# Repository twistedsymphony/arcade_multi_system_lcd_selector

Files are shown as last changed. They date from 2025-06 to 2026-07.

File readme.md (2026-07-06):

# twistedsymphony's universal multi-kit LCD Selector (aka CAERTF-MS)

# F.A.Q.

**What is this thing?**

This is a small remote selector that can be adapted and used on DIP-switch based arcade multi-systems. 
Once the device is configured and installed, rather than selecting your game by setting dip switches, users can push the "Up" (D0) and "Down" (D2) buttons to navigate visually through the game list, then push "Select" (D1) to select the game. The selector will then hold the arcade board in reset and electrically configure the dip switches before releasing reset allowing the selected game to boot.
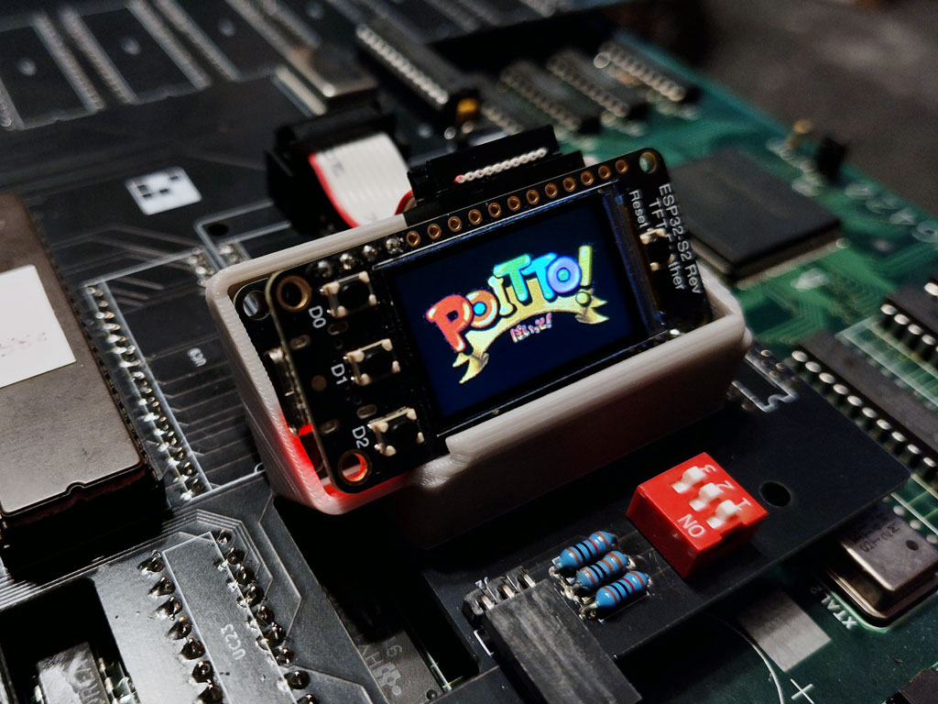
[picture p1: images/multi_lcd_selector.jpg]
multi_lcd_selector


**What is a DIP-switch based arcade multi-system?**

It's pretty niche, but some arcade games share the same electronics and only really have differing software. Arcade Enthusiests have designed and built "multi-systems" that allow switching out the software so that rather than having a whole separate set of electronics for each game, one set of electronics can play multiple games. The simpliest of these multi-systems will often use Dip-switches to set the game, which is cheap and effective but can be quite clumsy and unintuitive to use.

**Why was this made?**

Selecting your game using dip-switches can be frustrating, annoying, and very much non-intuitive. You typically need to have a little chart near by that tells you how to set the dip switches for the game you want to play, and if you want to switch games you have to power everything down to change it. Doing this while your arcade PCB is inside of an arcade cabinet means you sometimes have to be a contortionist with night-vision and the dexterity of a bomb-diffusal expert just to change that game you're playing. A selector like this one, that is easy to use and understand, solves most of those problems. 

This is being made open source in the hopes that future multi-systems that get developed by anyone in the community can easily incorporate support for this benefiting both the functionality of their multi and the users in the community. 

**What features/functinoality does this have?**

You get a full-color TFT display to show the game logos, you get 3 buttons: up, down, and select, so you can scroll through the game list and select the game you'd like to play. Selecting the game displays a loading screen while it resets the PCB and virtually configures the dip switches for game you selected. If an image isn't found it it will display the title of the game as text on the screen, and can seemilessly scroll between text and image based entries. It uses a standard 10-pin IDC ribon cable connection to the multi so you can remote mount the selector outside the cab by simply buying a cable long enough for your setup.

Through the menu configuration file you can control:
* what image is displayed with each game
* what image to display for the loading screen
* what text is to be displayed if an image isn't available
* what the dip configuration is for each selection
* what order you would like the games to appear in (you can even have the same game appear multiple times, in multiple places or with multiple names or images if you like)
* which games you would like displayed in the list or not displayed in the list
* which game you would like to load by default when you first power on
* the amount of idle time before the menu to goes back to displaying the current running game if you scrolled without selecting anything and then stopped

See the section below on "reconfiguring the menu_config.json file" for details on how to adjust these settings.

future features:
* remember last game. The code has support to remember the last selected game on power down and select that game on next power up, but there's a bug that's preventing that from functioning
* Selection over WiFi from your phone or other devie. the selector has Wifi Support so this is possible, the software just needs to be built.

**How Difficult is this to setup and use?**

If you're designing and building a multi kit this will add exactly $0 to your production costs. For the bare minimum support you simply need to add a 10-pin header footprint to your PCB for the selector and a 1-pin header footprint for a reset wire. This adds no cost to production and maybe an hour (not even) of your time to add the header to your schematic and PCB layout. I've even provided pre-configured footprints to allow mounting of the selector directly to your PCB if you have the room for it. If you want stronger support still you can spend a few extra cents per PCB and solder in the headers to each of the footprints you added to make use of the LCD selector completely plug and play for your users.

If you're a user of multis the difficulty varies depending on the multi-kit, setting up the kit at most would require soldering of some simple through-hole parts. The selector itself uses an off-the-shelf display and MCU unit from Adafruit coupled with a custom designed interface PCB that is open source and you can send the design files out and have made completely, or find someone selling them. Installing the software is as simple as copying files over to a USB thumb drive.

**Can this be used on multi-kits that weren't designed for it?**

Potentially, from an electrical standpoint this can be used with any multikit design to select games by up to 7 dip-switches (or jumpers). The challenge is wiring it up in a way that doesn't look like a science-experiment, which will vary greatly depending on the multi. The software is fully customizable, in addition to the "menu" config file there is a separate "multi" config file that allows you to specify the parameters of the multi for the software to tailor itself for it's use without any code changes.

# Putting Together a Selector as a Multi-Kit User

## Building a Selector
To piece together a selector you need 3 parts:
1. An Adafruit ESP32-S2 Reverse TFT Feather, which can be [purchased directly from Adafruit](https://www.adafruit.com/product/5345)
2. An CAERTF-MS Interface PCB, the schematics footprint, BOM, and ready-to-go production files are available within this repo
3. a 10-pin IDC cable. Multi-kits designed for selector mounting using the footprints in this repo are designed to utilize a 1.5in (38mm) length cable which can be [purchased from Adafruit](https://www.adafruit.com/product/556) though any 10-pin (2x5 female to female) IDC cable should work.

the Adafruit ESP32-S2 Reverse TFT Feather unit includes 2 male pin header rows, you will need to solder these to the unit to allow it to plugin to the CAERTF-MS interface PCB. While looking at the LCD with USB port on the left you will want to solder the entire bottom row of pins and the first 4 pins on the top left to allow it to plug into a CAERTF-MS Interface PCB and complete the assembly. 

## Setting up a Software release on a new Selector.
1. With the selector disconnected from both the multi-kit and the CAERTF-MS interface board, and disconnected from any power source, connect a USB-C cable between the selctor and your PC. 
2. If this is the first time configuring the selector the display on the selector should say "Adafruit Feather" with some information about the button and "battery" voltages, this is just the default software loaded. On the back of the display you should see a green and blue LED and there is a small reset button next to the USB port, you'll want to click this button once to reset, then double click it to put it into bootloader mode. If successful you should see the screen change and your PC should recognize a USB storage device called "FTHRS2BOOT" If not, attempt the reset button sequence again (the timing between the first click to reset and the subsequent double click can be tricky to get right)
3. Copy the latest Circuit Python .UF2 file file to the root of the "FTHRS2BOOT" drive. You can [get this file from the circuitpython website]( https://circuitpython.org/board/adafruit_feather_esp32s2_reverse_tft/) (at the time of this writing 9.2.8 was the lastest version and known to work)
4. Once the file has been copied over, the display should automatically restart and it will display some small white text on the screen and you will now see a new USB storage device attached to your computer called "CIRCUITPY"
5. Copy the entire content of a release file over to the root folder of the CIRCUIT PY drive. your computer will likely ask if you want to overwrite code.py, select yes to overwrite.

Releases should include:
  * code.py from the he /source directory here on github 
  * multi_config.json and menu_config.json configuring the selector specificlly to your multi kit
  * a /lib folder with the adafruit_display_text library
  * a /images fold that includes the loading.bmp image along with .bmp images for each game the multi supports.
4. you can now test out the menu to make sure it has the games you expect and see how it functions before connecting it to your multi. If you'd like to ajust settings in "menu_config.json" file you can do so to configure the menu to your liking and confirm those changes work while you still have it hooked up to your PC. it is NOT recommended to adjust the multi_config.json settings as these determine the electrical configurain for the multi.
5. once you're done simply unplug the USB-C cable from the display and now the software on the selector is ready for the multi.

**NOTE: Do not connect the USB-C on the Selector at the same time the 10-pin connector is attached to the Multi PCB** Doing so risks damaging your USB host device. The interface PCB has some protections to help prevent voltage back-feed from the USB port to the Multi-PCB but there are no protections to stop voltage back feed from the multi-PCB to the USB port as such there is risk of damage to your USB Host device.

## Installing a Selector onto your Multi
1. Follow the steps above to build the selector hardware
2. Follow the steps above to install the software on the selector
3. Ensure that all Dips switches on your multi are set to "OFF" (0) and that any rotary selectors are set to position "0". Alternatively, you can completely remove any dips or rotary switches from your multi-PCB (if you set any of these switches to other positions it causes that dip to perminently register as "on" resuling in different selections being made other than the game you selected on the LCD selector)
3. Plug the Adafruit ESP32-S2 Reverse TFT Feather into the CAERTF-MS Interface PCB, Make sure the USB-C port is disconnected (**Do not connect the USB-C on the Selector at the same time the 10-pin connector is attached to the Multi-PCB** the interface PCB has some protections to help prevent voltage back-feed from the USB port to the Multi-PCB but there are no protections to stop voltage back feed from the multi-PCB to the USB port as such there is risk of damage to your USB Host device.)
4. Connect the 10-pin IDC cable between the selector and the appropriate header on your multi-PCB
5. (optional) Install any mounts or brackets that may be avalable for your particular multi

## Making Images for the Selector
Images for the selector should be 240x135 pixels and .bmp format. it's recommended to used 8-bit indexed color format for the .bmp as this should set the file size to 33kb for each image. This is small enough to support 32 images for multis with 5-dip switches (32 game slots) or less. For multis with 6 dips (64 game slots) or 7 dips (128 game slots) you will likely need to get creative with lower bit-depth color or use text rather than images for some games.

While BMP files are larger the processing speed required to decode .jpg or .png compression on images takes about 1-2 seconds per image load which dramatically slows down menu navigation making the game selection experience feel extremely laggy. BMP was chosen as it is essentially uncompressed and is able to load instantly and at 8-bit indexed color is still small enough to support images for all games on nearly all dip-switch based multis.

## reconfiguring the menu_config.json file
The Configuration files on this multi are stored in a json format. You can use any plain text editor (such as notepad) to edit a .json file. If the formatting is incorrect or if any value is set incorrectly the multi will display an error on the screen explaining the issue rather than booting to the menu. It's highly recommeded that you use an existing working menu_config.json file and modify when developing a configuration file for a new multi, or adjusting your preferences for an existing multi. this will help you understand the format and parameters.

"games" are identified with a text string, I use the mame rom name for simplicity and consistency but any string of text can be used so long as it's used consistently through the config file. image file paths are always from the root of the device, and by default will use the "/image/filename.bmp" path and format.

There are three sections to the menu_config.json file, the main configuration which describes how the menu functions, the "game_order" list which simply describe the order that the games will apepar in the menu, and the "gamedefs" list which describes each game, it's title, which image it uses, and it's hex value in dips or on a rotary selector.

The main config has the following value and parameter pairs:
* multi_name: [string] This is simply a string of text to help identify which multi the menu is for, it's not used by the multi at all and really just useful to human readers of the config file.
* default_game: [string] this is the game that will start by default when the multi is powered on, it must be set to a value that matches a game identifier in the gamedefs section. if you do not have a preference it is recommended to set this to which ever game occupies position 0 (all dips off) as that will allow initial board bring up about 2 seconds faster.
* retain_selection: [boolean] this is a true or false value, when true the default_game will be ignored and instead the last game selected when the multi was powered off will be selected by default on next power-on (currently this feature is not functioning)
* idle_timeout: [decimal] this is the number in seconds that when scrolling through the menu without selecting a game that the selector will consider "idle" and return the display to showing the currently loaded game. default value of: 10
* debounce_delay: [decimal] this is number in seconds that subsequent button presses will be ignored. necessary to prevent accidental double taps. default value of: 0.2
* loading_image: [string] the file name and path to the .bmp file that will be used for the loading image when loading a new game. If the file specified does not exist plain text will be displayed instead. default value of: "/images/loading.bmp"
* text_color: [string] the hex value describing the color of the text on the screen when text is displayed instead of an image. default value of "0xFFFFFF"
* left_margin: [integer] the left margin in pixels when text is used on screen instead of an image. default value of: 10
* top_margin: [integer] the top margin in pixels when text is used on screen instead of an image. default value of: 60

The game_order section is simply a json array of all of the game identifiers and the order you wish to see them displayed in the menu. the game identifiers must match those specified in the "gamedefs" section. You may opt to exclude games here if you do not want them to appear on the menu, similarly you can include games in the game order multiple times if you wish for them to appaer multiple times on the menu rotation. The selector offers infinite menu rotation in either direction so the last game appears before the first game and the first game appears after the last game when scrolling.

the gamedefs section is a nested object where gamedefs includes a game object for each game available on the selector. each game object is labeled with a game id. As mentioned above I recommend using mame rom names for the game id for simplicity and consistency, but anything can be used. the only rule is that each game object must have a unique name.

each game object has 3 values:
* title: [string] The display text for the game title to use if an image file is not available. Multiple games can have the same title, though it's not recommended as there would be now way to tell the entries apart when using the menu. This text can be as long as you like, it will auto-resize the text to fit. However long games will be harder to read.
* image: [string] the file name and path to the image file associated with the game. I recommend naming your image files the same as the game id for simplicity and consistency. Multiple games can use the same image, though it's not recommended as there would be no way to tell the entries apart when using the menu. See the section above for details on how to make appropriate images for the selector.
* dip_val: [string] this is the value in hex that identifies which position on a rotary selector, or which dip-switch configuration is associated with the particular game. So for instance for a 4 position dip-switch a value of "1" will be translated to a dip configuraiton of "0001" and a value of "C" will be translated to "1100". Multiple games can use the same dip postion. So you could for instance have a game appear twice with two different names or two different images but use the same dip value.

# Adding Support for this Selector to your Multi as a Multi-Kit Developer
If you're designing and building a multi kit this will add exactly $0 to your production costs. For the bare minimum support you simply need to add a 10-pin header footprint to your PCB for the selector and a 1-pin header footprint for a reset wire. This adds no cost to production and maybe an hour (not even) of your time to add the header to your schematic and PCB layout. I've even provided pre-configured footprints to allow mounting of the selector directly to your PCB if you have the room for it. If you want stronger support still you can spend a few extra cents per PCB and solder in the headers to each of the footprints you added to make use of the LCD selector completely plug and play for your users.

A version of the CAERTF-MS interface board has been created for Apocalypse Multi Kits and released to it's own repo: https://github.com/twistedsymphony/apoc_arcade_multi_system_lcd_selector

## Electrical Pinout for 10-Pin header
The header on both the caertf-ms interface board as well as the header expected on the multi should use a 2.54mm pitch 10-pin male shrouded header with the alinment key in front of pin 5 as shown in the image below.

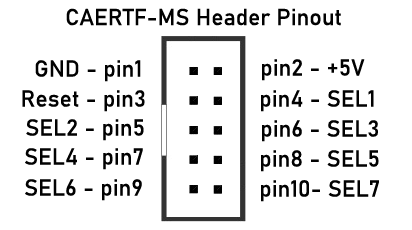
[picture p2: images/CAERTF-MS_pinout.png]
caertf-ms_pinout


* *Pin 1* is a Gound pin
* *Pin 2* is a +5V supply from the multi PCB to power the Selector, this is passed through a diode to ensure powe flow only from the multi to the selector and not back feed into the multi from the selector.
* *Pin 3* is the reset signal from the selector to the multi PCB, this should be routed to a header somewhere on the multi so that the user can install a reset wire to the original game PCB. This pin is driven to Ground when attempting to hold reset with Open Drain when not in reset. It is driven by a [Ti SN74LVC1G07DBVR open drain buffer](https://www.ti.com/lit/gpn/sn74lvc1g07)
* *Pins 4-10* are the selector signal pins, these are driven either high (+5v) or low (GND) by a [Ti LC245A buffer chip](https://www.ti.com/lit/ds/symlink/sn74lvc245a.pdf) It is assumed that SEL1 represent the lowest address controlled by the selector additional SEL pins are utilized in order to cover the number of controlled addresses, for instance if your multi has 3 dips then you will use SEL1, SEL2, and SEL3 and leave SEL4-SEL7 disconnected.

## Footprints and mounting considerations
When adding support for this selector on your multi you may opt to use a generic 2.54mm pitch 10-pin male shrouded header footprint on your multi PCB, however special footprints have been developed that can enable mounting of the selector directly to the PCB. There are 8 footprint files in this repo. uniquely identified by "1pos" "2pos" "3pos" and "4pos" to specifies the number of mounting positions that they accomidate. For instance 1pos allows only 1 position for the selector can be mounted while 2pos enables 2 positions offset 90 deg from each other giving your users more mounting options (provided your multi PCB has enough space to accomidate additional mounting options). Each position also has "co" and "nco" variants for "cut-outs" and "no cut-outs". Footprints with cut outs have edge cuts built into the footprints to allow the through-hole pins of the caerft-ms interface pcb to passthrough the multi-pcb so that the PCBs can be mounted directly together with screws without concern of the through-hole solder joints contacting the multi-pcb. the no-cut-outs variants are missing these features and would require either 1.6mm or taller spacers on each screw, or the use of a small 3D printed spacer (included in this repo) to mount the selector to the footprint without the through-hole parts making contact witht he multi-pcb. All footprints are designed to use a IDC cable of 38mm (1.5in) or longer which can be [purchased from Adafruit](https://www.adafruit.com/product/556) though any 10-pin (2x5 female to female) IDC cable should work. An example of a 4-position no cut out footprint with an interface board attached can be seen below.

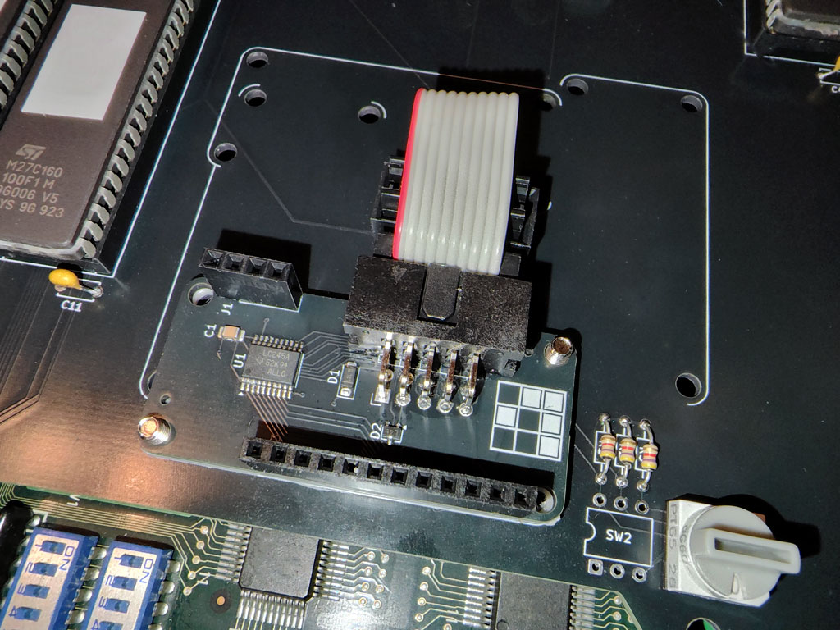
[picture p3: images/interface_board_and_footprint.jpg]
interface_board_and_footprint


In addition to directly mounting a selector to the footprint a 3D printed "cradle" has also been created (available in this repo) that can accomodate a selector, this holds the selector at a 45 deg angle for easier viewing and allows the selector to be placed in the cradle for storage or easily removed but the user without any tools. An example of a cradle mount can be seen below.
multi_lcd_selector

## Configuring the multi_config.json File
The multi config has the following value and parameter pairs:
* multi_name: [string] This is simply a string of text to help identify which multi the config file is for, it's not used by the multi at all and really just useful to human readers of the config file.
* dip_bits: [integer] This is the number of dip-switch positions that the multi-kit utilizes
* dip_on: [string] Should be set to either "1" or "0", This specifies wether a dip switch being in the "on" position is normal (on = 1, or +5V) or inverted (on = 0, or GND)
* reset_open_drain: [boolean] this should be set to "true" or "false" and determines whether the Adafruit module itself provides and open drain for the rest signal. This should be set to "false" when using the caertf-ms interface pcb as the interface pcb itself has a buffer providing the open drain. it should only be set to true if using the Adafruit unit directly without any interface PCB or if using your own interface PCB that requires this setting adjusted. default vale: false
* dip_bits_reversed: [boolean] This determines the bit order of the dip switches, when "true" SEL1 is the least significant bit, when "false" SEL1 is the most significant bit, with the total bits determined by the "dip_bits" setting above. default vale: false

## Reset wire recommendations
(Additional Details coming soon)

## Example Dip Based Multi-Kit Schematic
(Additional Details coming soon)

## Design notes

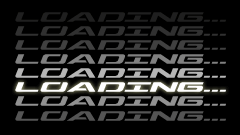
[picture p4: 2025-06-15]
source/images/loading.bmp

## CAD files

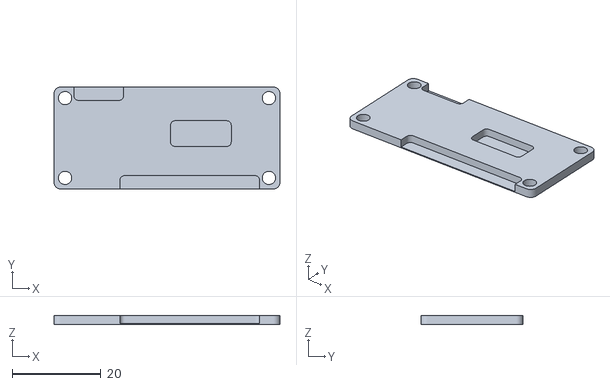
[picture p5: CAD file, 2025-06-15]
schematics/mounts/multi_lcd_selector_spacer.STL
51.0 x 23.0 x 2.00

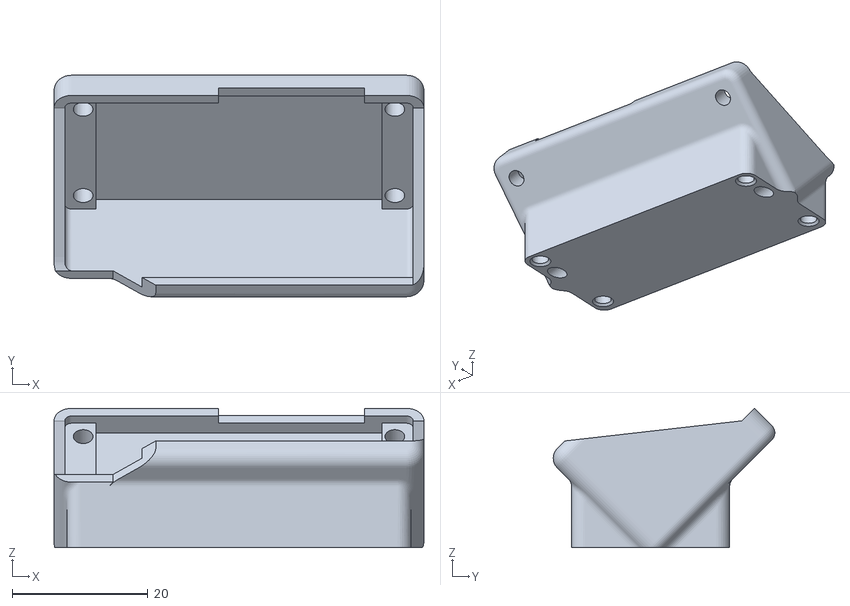
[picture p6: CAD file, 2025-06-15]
schematics/mounts/multi_lcd_selector_cradle.STL
54.6 x 32.7 x 20.6

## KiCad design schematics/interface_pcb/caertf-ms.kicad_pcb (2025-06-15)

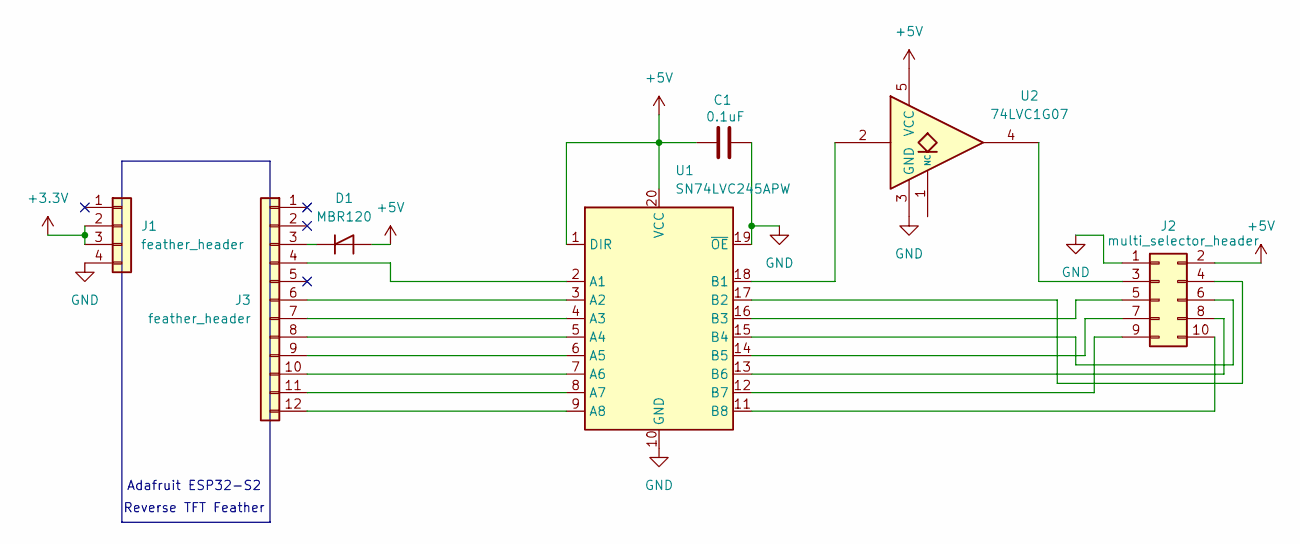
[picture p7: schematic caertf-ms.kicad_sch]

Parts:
C1: 0.1uF; C_0805_2012Metric_Pad1.18x1.45mm_HandSolder; JLCPCB Part # C5451689
D1: MBR120; D_SOD-123; JLCPCB Part # C130880
J1: feather_header; PinSocket_1x04_P2.54mm_Vertical; JLCPCB Part # C7509546
J2: multi_selector_header; PinHeader_2x05_P2.54mm_Horizontal; JLCPCB Part # C2682217
J3: feather_header; PinSocket_1x12_P2.54mm_Vertical; JLCPCB Part # C25687189
U1: SN74LVC245APW; TSSOP-20_4.4x6.5mm_P0.65mm; JLCPCB Part # C7848
U2: 74LVC1G07; SOT-23-5; JLCPCB Part # C7829

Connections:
+3.3V: J1.2, J1.3
+5V: C1.1, D1.2 (A), J2.2, U1.1 (DIR), U1.20 (VCC), U2.5 (VCC)
GND: C1.2, J1.4, J2.1, U1.10 (GND), U1.19 (~OE), U2.3 (GND)
unnamed: D1.1 (K), J3.3
unnamed: J2.3, U2.4
unnamed: J2.4, U1.17 (B2)
unnamed: J2.5, U1.16 (B3)
unnamed: J2.6, U1.15 (B4)
unnamed: J2.7, U1.14 (B5)
unnamed: J2.8, U1.13 (B6)
unnamed: J2.9, U1.12 (B7)
unnamed: J2.10, U1.11 (B8)
unnamed: J3.4, U1.2 (A1)
unnamed: J3.6, U1.3 (A2)
unnamed: J3.7, U1.4 (A3)
unnamed: J3.8, U1.5 (A4)
unnamed: J3.9, U1.6 (A5)
unnamed: J3.10, U1.7 (A6)
unnamed: J3.11, U1.8 (A7)
unnamed: J3.12, U1.9 (A8)
unnamed: U1.18 (B1), U2.2

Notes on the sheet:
Adafruit ESP32-S2
Reverse TFT Feather

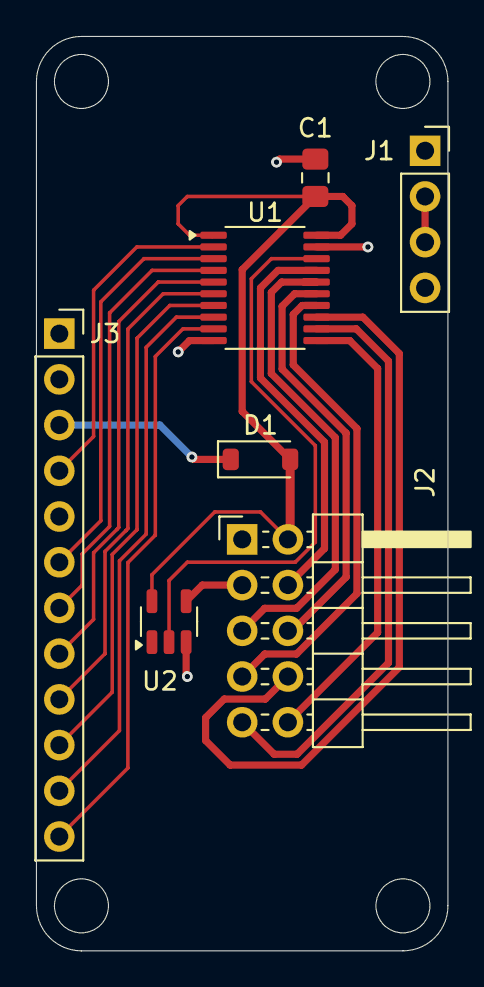
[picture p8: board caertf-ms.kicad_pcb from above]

Board: 2 copper layers, 22.9 x 50.8 mm, 7 parts (0 on the bottom side), 21 nets.

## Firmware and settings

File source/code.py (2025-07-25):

import board
import digitalio
import displayio
from displayio import OnDiskBitmap
import json
import time
import terminalio
from adafruit_display_text import label


# function: change the currently dispalyed image
def display_bmp(filename, alt_text):
    global tile_grid

    if tile_grid is not None:
        main_group.pop()  # Remove previous tilegrid
    try:
        bitmap = OnDiskBitmap(open(filename, "rb"))
        tile_grid = displayio.TileGrid(bitmap, pixel_shader=bitmap.pixel_shader)
        main_group.append(tile_grid)
    except Exception as e:
        screen_width = 240  # dispaly width in pixels
        char_width = 6  # character width in pixels (estimated)
        text_pixel_length = (len(alt_text) * char_width) + left_margin
        scale_factor = screen_width // text_pixel_length
        scale_factor = max(1, scale_factor) # Ensure scale is at least 1
        text_area = label.Label(terminalio.FONT, text=alt_text,color=text_color,scale=scale_factor)
        text_area.x = left_margin
        text_area.y = top_margin
        main_group.append(text_area)


# function: Load A game from the specified index
def select_game(game_index):
    global loaded_game
    loaded_game = current_index  # set the current indexed game as the loaded game
    display_bmp(loading_image, "Loading...")  # display loading
    reset_out.value = False  # hold game in reset

    # set dips
    dip_val_bin = dip_hex_to_bin(game_list[loaded_game]["dip_val"])
    for i, bit in enumerate(dip_val_bin):
        gpio_pins[i].value = True if bit == dip_on else False

    time.sleep(reset_time)  # wait for reset timer
    reset_out.value = True  # release reset
    display_bmp(game_list[loaded_game]["image"], game_list[loaded_game]["title"])  # replace loading image with game image
    save_selection(loaded_game)  # save the selection for use on reboot


# converts the hex dip val in the json to binary string
def dip_hex_to_bin(dip_val_hex):
    dip_val_int = int(dip_val_hex, 16)
    
    #dip_val_int &= (1 << dip_bits) - 1 # keep only the lowest dip_bits bits
    
    dip_val_bin = f'{dip_val_int:0{dip_bits}b}'
    
    if dip_bits_reversed:
      dip_val_bin = ''.join(reversed(dip_val_bin))
      
    return dip_val_bin


# function save the selected game index for use on reboot
# TODO: Fix this, this function doesn't currently work (permissions/write enabled?)
def save_selection(index):
    try:  # this will fail when USB is connected, so we will try and ignore if fail
        with open("/saved_index.txt", "w") as f:
            f.write(str(index))
    except Exception:
        pass

# configure reset GPIO (do this first so we can hold in reset during rest of the load
reset_out = digitalio.DigitalInOut(board.D13)
reset_out.switch_to_output(
    value=False,  # start LOW (reset on boot)
    #drive_mode=digitalio.DriveMode.OPEN_DRAIN #this is added on optionally later once config is parsed
)

# configure selector GPIOs
gpio_pins = []
gpio_pins.append(digitalio.DigitalInOut(board.D11))  # SEL1
gpio_pins.append(digitalio.DigitalInOut(board.D10))  # SEL2
gpio_pins.append(digitalio.DigitalInOut(board.D9))  # SEL3
gpio_pins.append(digitalio.DigitalInOut(board.D6))  # SEL4
gpio_pins.append(digitalio.DigitalInOut(board.D5))  # SEL5
gpio_pins.append(digitalio.DigitalInOut(board.D4))  # SEL6
gpio_pins.append(digitalio.DigitalInOut(board.D3))  # SEL7
for pin in gpio_pins:  # loop through the selection pins
    pin.direction = digitalio.Direction.OUTPUT  # configure them as outputs


# configure buttons
button_up = digitalio.DigitalInOut(board.D0)
button_up.switch_to_input(pull=digitalio.Pull.UP)
button_down = digitalio.DigitalInOut(board.D2)
button_down.switch_to_input(pull=digitalio.Pull.DOWN)
button_select = digitalio.DigitalInOut(board.D1)
button_select.switch_to_input(pull=digitalio.Pull.DOWN)


# load multi_config.json
try:
    with open("/multi_config.json", "r") as f:
        multi_config = json.load(f)
    dip_on = multi_config["dip_on"]  # determines if a dip_on position is high (1) or low (0)
    dip_bits = multi_config["dip_bits"]  # determines the number of dip swiches that the multi supports
    dip_bits_reversed = multi_config["dip_bits_reversed"]  # when true dips start with least significant bit
    reset_time = multi_config["reset_time"]  # How long to hold in reset when loading new game
    if multi_config["reset_open_drain"]:
        #reconfigure reset pin
        reset_out.switch_to_output(
          value=False,  # start LOW (reset on boot)
          drive_mode=digitalio.DriveMode.OPEN_DRAIN #add open drain
        )
    
except Exception:
    print("Error Loading multi_config.json")
    while True:
        pass  # stop here


# load menu_config.json
game_list = []
try:
    with open("/menu_config.json", "r") as f:
        menu_config = json.load(f)
    debounce_delay = menu_config["debounce_delay"]
    idle_timeout = menu_config["idle_timeout"]  # How long before reset? (seconds)
    loading_image = menu_config["loading_image"]  # the image file for the loading screen
    text_color = int(menu_config["text_color"], 16)  # color of the alt_text
    left_margin = menu_config["left_margin"]  # offset from the left edge of the alt_text
    top_margin = menu_config["top_margin"]  # offset from the top edge of the alt_text
    for game in menu_config["game_order"]:
        game_list.append(menu_config["gamedefs"][game])
        if game == menu_config["default_game"]:  # initial game loaded
            loaded_game = len(game_list)-1
    for game in game_list:
        dip_val_bin = dip_hex_to_bin(game["dip_val"])
        if len(dip_val_bin) > dip_bits:
            raise Exception(f"dip_val {game['dip_val']} out of range")
        if not game["image"]:
            raise Exception("image property missing from gamedef")
        if not game["title"]:
            raise Exception("title property missing from gamedef")
except Exception as e:
    print("Error Loading menu_config.json")
    print(f"Exception: {e}")
    while True:
        pass  # stop here


# load_last_selected_game
try:
    if menu_config["retain_selection"]:  # if the option to retain the last loaded game is set
        with open("/current_image.txt", "r") as f:  # open the saved index file
            content = f.read().strip()  # clean it up
            saved_index = loaded_game  # set defailt if the following checks fail
            if content.isdigit():  # only allow positive integers
                saved_index = int(content)  # convert the text to int
            if saved_index < len(game_list):  # make sure the index is inbounds
                loaded_game = saved_index  # set the loaded game
except Exception:
    pass  # do nothing

# configure the display handling, we do this after loading json so we can display errors on console
display = board.DISPLAY  # setup built-in display
tile_grid = None
main_group = displayio.Group()
display.root_group = main_group

# first run executions
current_index = loaded_game  # set the default menu selection to the current loaded_game
select_game(loaded_game)  # sets the initial game
last_interaction_time = time.monotonic()  # Track time of last button interaction


# main program loop
while True:
    now = time.monotonic()  # capture the current time of this loop

    if button_down.value:  # NEXT Game Button
        current_index = (current_index + 1) % len(game_list)
        display_bmp(game_list[current_index]["image"], game_list[current_index]["title"])
        last_interaction_time = now  # reset idle timer
        time.sleep(debounce_delay)  # debounce delay

    if not button_up.value:  # PREVIOUS Game Button
        current_index = (current_index - 1) % len(game_list)
        display_bmp(game_list[current_index]["image"], game_list[current_index]["title"])
        last_interaction_time = now  # reset idle timer
        time.sleep(debounce_delay)  # button debounce

    if button_select.value:  # SELECT Game Button
        select_game(current_index)  # load the selected game
        time.sleep(debounce_delay)  # button debounce

    # Check for idle timeout
    if now - last_interaction_time > idle_timeout:
        if current_index != loaded_game:
            current_index = loaded_game
            display_bmp(game_list[current_index]["image"], game_list[current_index]["title"])

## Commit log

2025-06-15 Add files via upload
    Added Footprints and Interface Board Schematics
    [caertf-ms.kicad_pcb, caertf-ms.kicad_sch]
2025-06-15 Add files via upload
    Added STL printable mount files
    [multi_lcd_selector_cradle.STL, multi_lcd_selector_spacer.STL]
2025-06-17 Update code.py
    Fixed typos in comments
    [code.py]
2025-06-22 Updated Footprints
    Updated footprints to improve component outline and Pin 1 identification
2025-07-25 Added Dip reverse order multi config option
    - dip_bits_reversed parameter has been added to multi_config.json allowing the dip bits to be interpreted in reverse order.
    [code.py]
